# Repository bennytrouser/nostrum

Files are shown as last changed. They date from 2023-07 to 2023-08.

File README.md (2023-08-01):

# Nostrum
A 32 key ergo split keyboard with minimal splay.
- 3° Splay on pinky and ring columns
- Inspiration from the [Hummingbird](https://github.com/PJE66/hummingbird) style [Berylline](https://github.com/jcmkk3/trochilidae#berylline) by [jcmkk3](https://github.com/jcmkk3)
- Created with the wonderful [ergogen](https://github.com/ergogen/ergogen) and KiCad7. Case files created with Autodesk Fusion360.

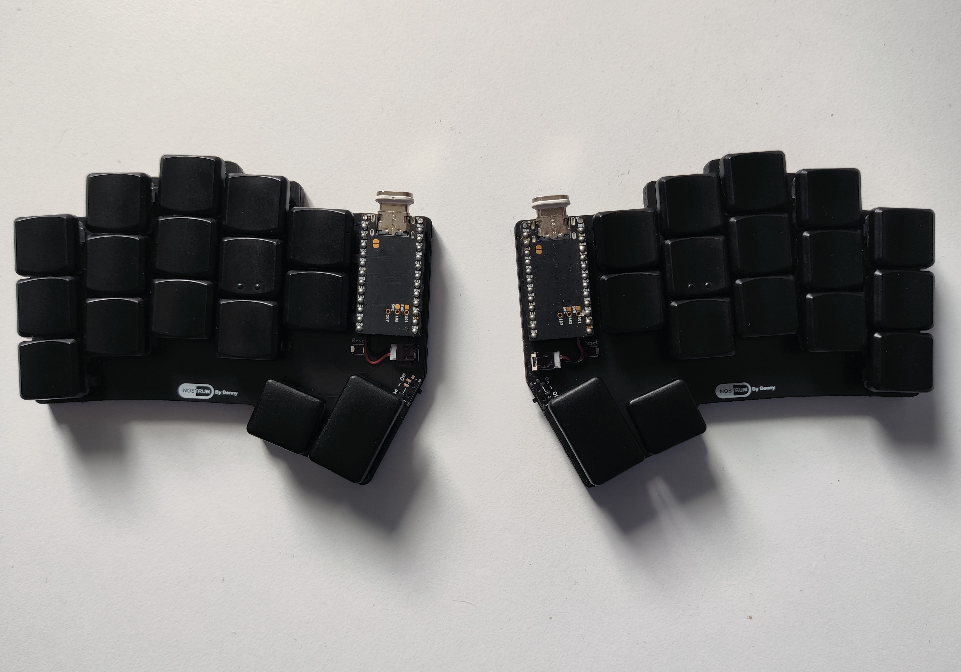
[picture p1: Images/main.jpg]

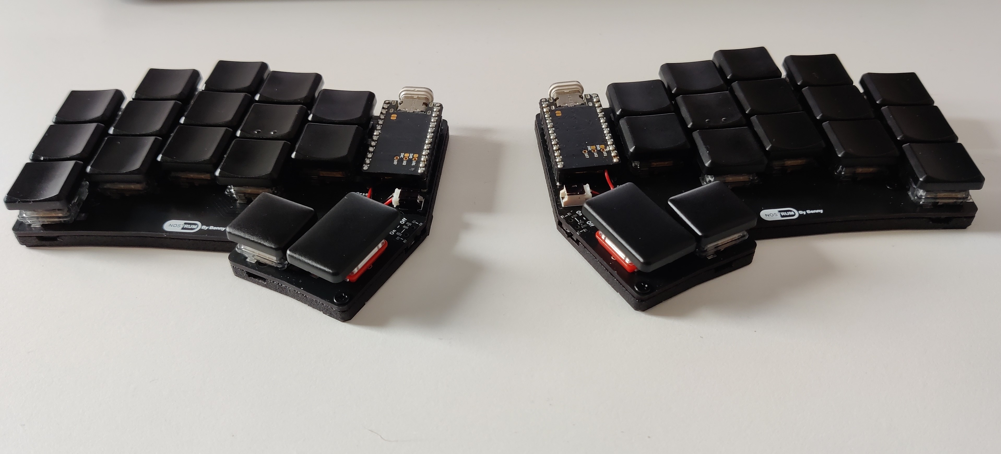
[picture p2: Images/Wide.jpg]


## PCB
| Top  | Bottom |
| --- | --- |
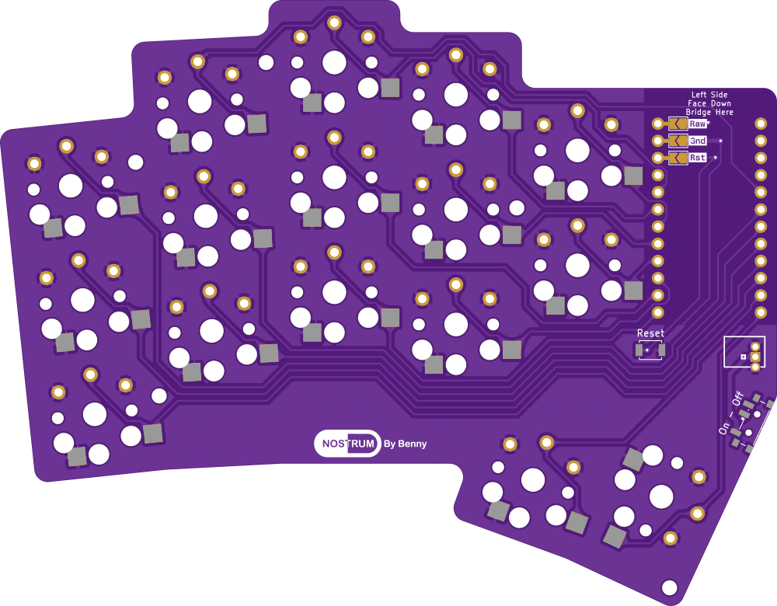
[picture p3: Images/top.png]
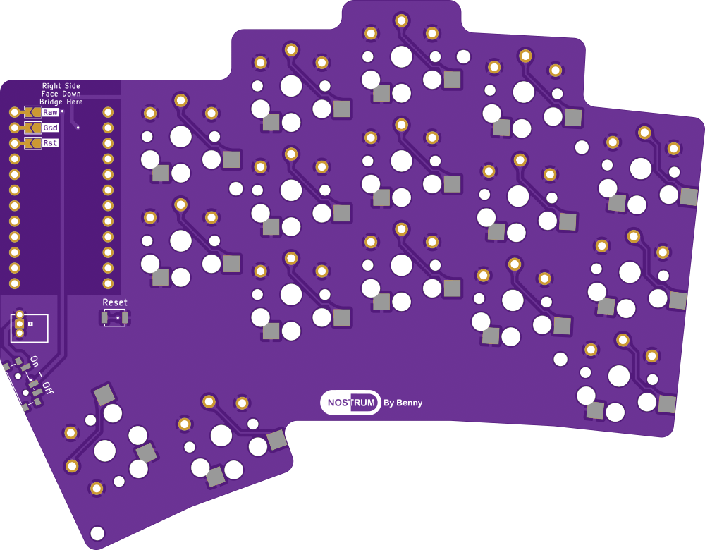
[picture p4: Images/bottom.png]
|   |  |

## Base Alpha Keymap
ColemakDH Based
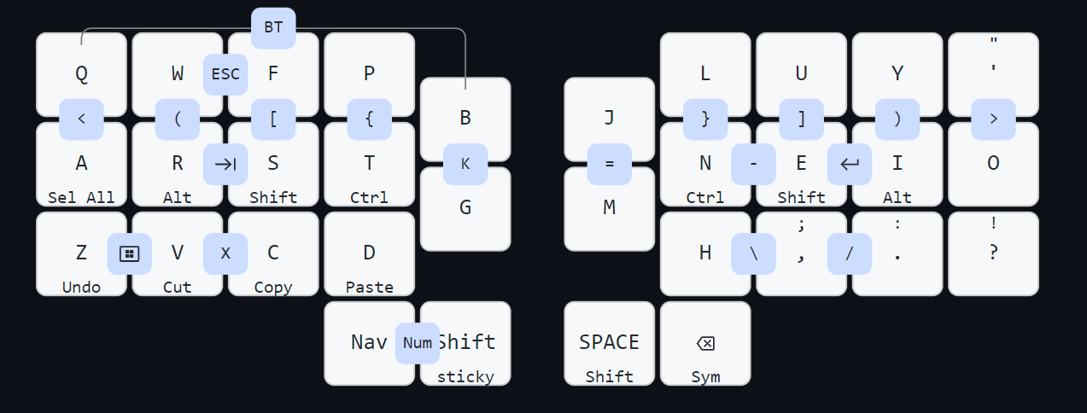
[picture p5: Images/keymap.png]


## Notes
- The reset and power switch can be mounted on either side. I think it works better with the case/bottom plate. 
- There is a hole on the base of the case to use a paper clip to activate the manual reset if mounted on the underside.
- The "feet" on the base are made from 1mm silicone rubber sheet as I prefer this to the standard bumpons.

## Warning
The original case was experimental. As such I have removed the files for the top part of the case and updated the bottom part that works great as a minimal bottom "tray". I have updated the STLs and pcb to avoid weakness on the mounting and to fix an issue with hotswaps causing fitment issues but I have not done a test print.

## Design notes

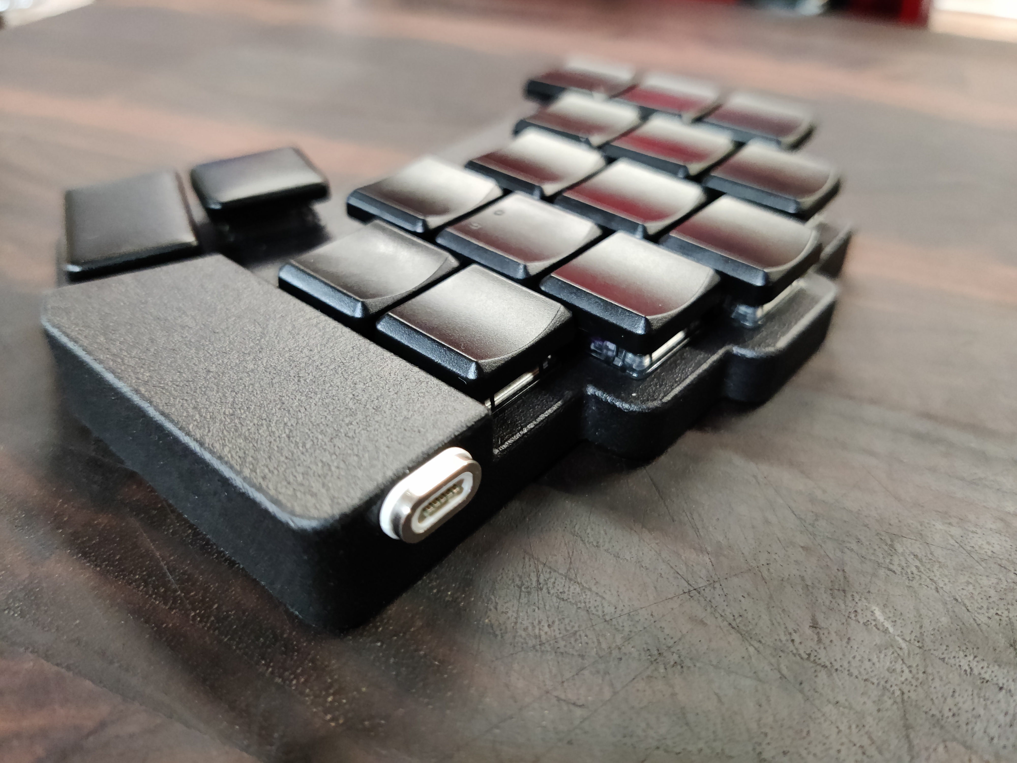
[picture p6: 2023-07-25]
Images/front.jpg

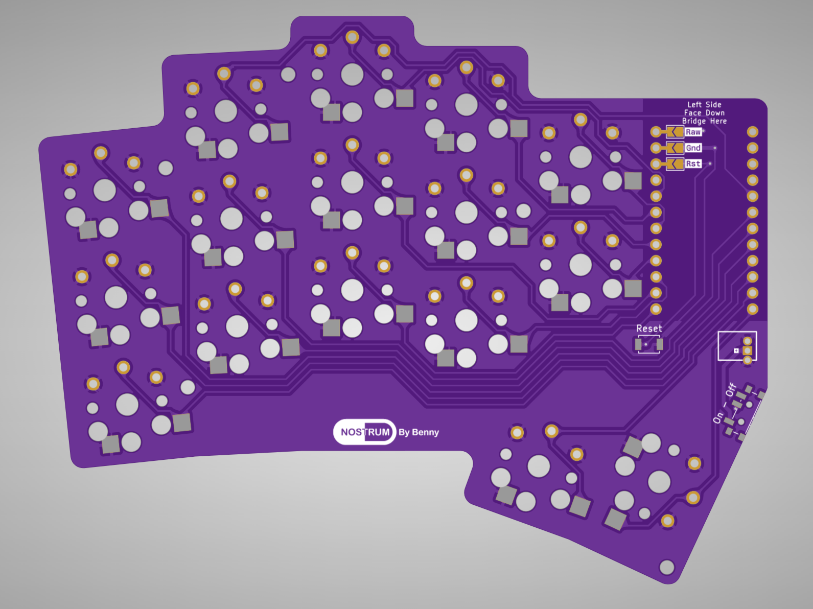
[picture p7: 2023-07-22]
Images/Nostrum_PCB.png

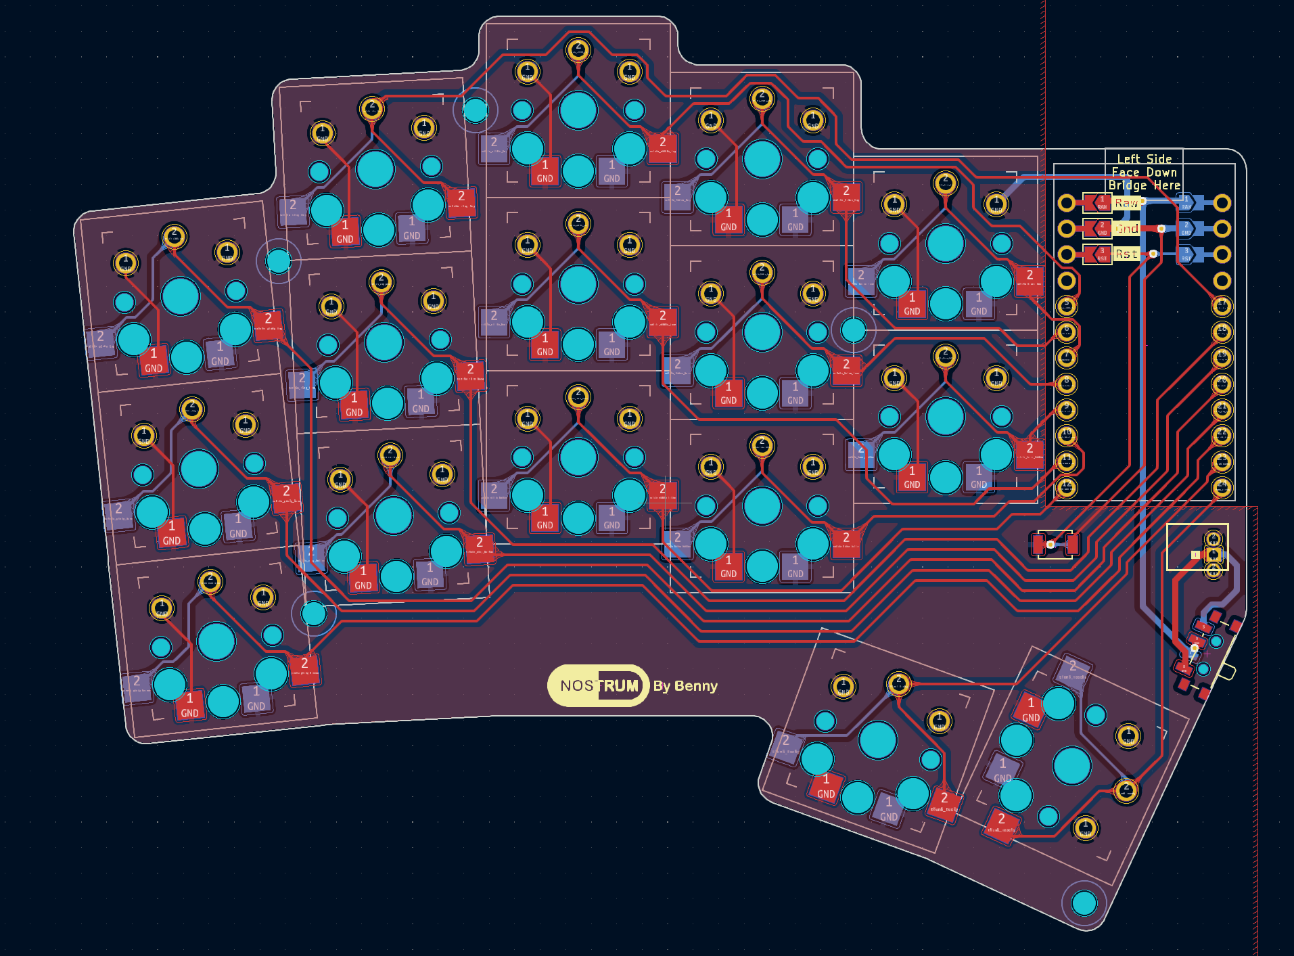
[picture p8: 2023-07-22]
Images/Nostrum_PCB_KiCad.png

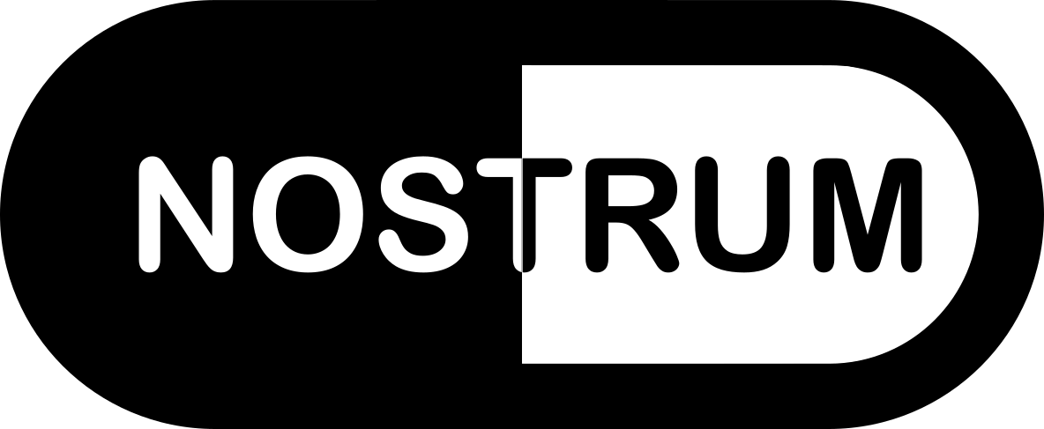
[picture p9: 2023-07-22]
Images/nostrum 2.png

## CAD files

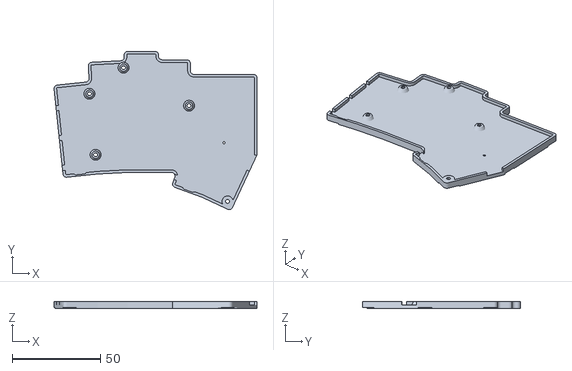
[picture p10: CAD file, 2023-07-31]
Files/Case STLs/Bottom Plate Left.stl
115.0 x 89.7 x 3.80

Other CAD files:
Files/Case STLs/Bottom Plate Right.stl

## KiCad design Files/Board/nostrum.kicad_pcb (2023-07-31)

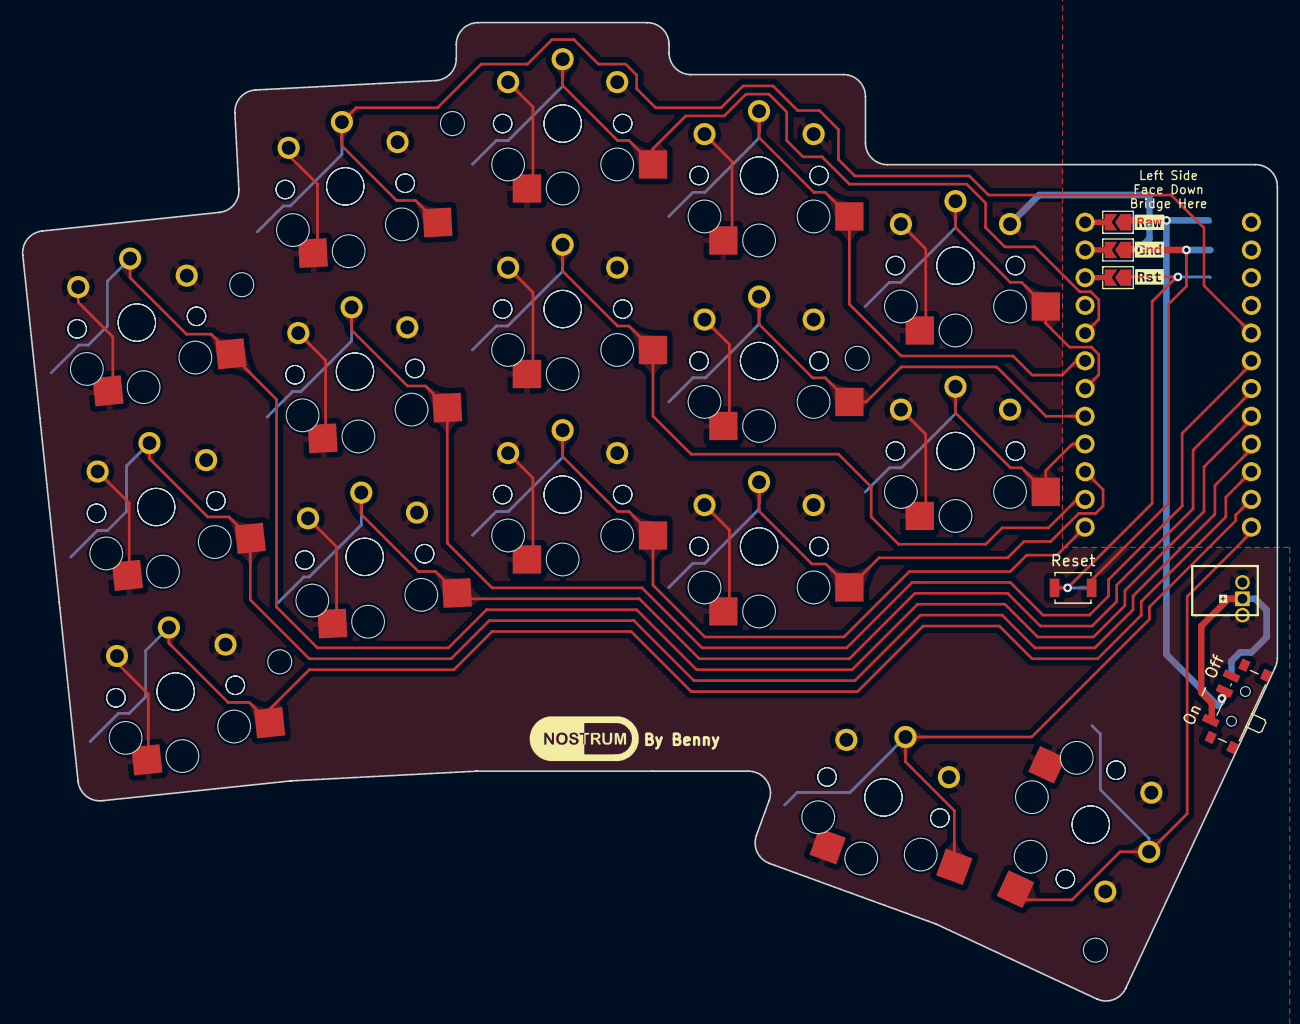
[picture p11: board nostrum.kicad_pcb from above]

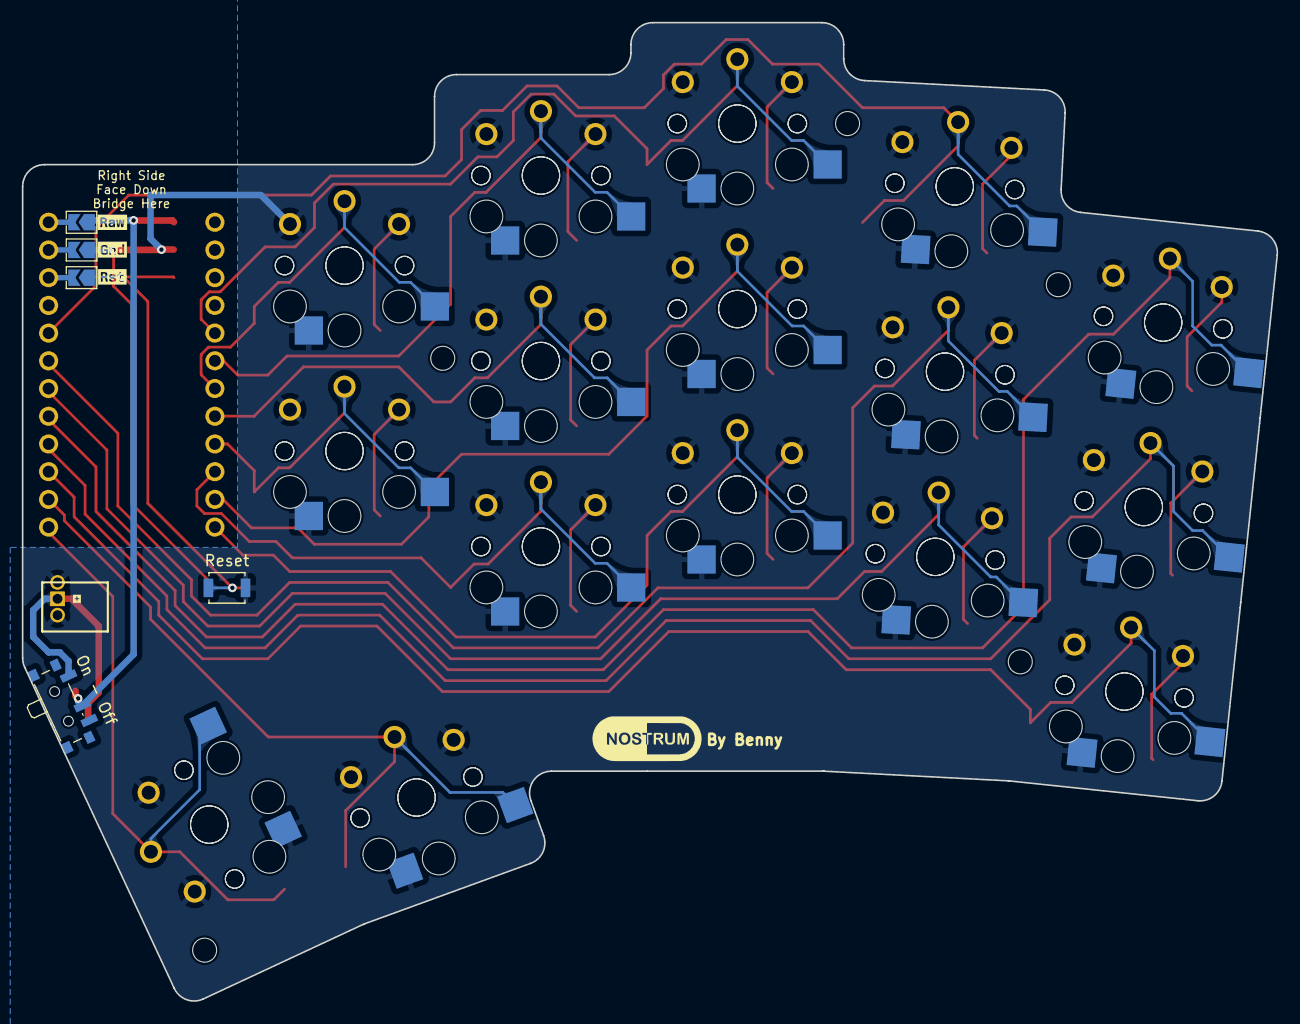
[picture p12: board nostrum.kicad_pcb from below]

Board: 2 copper layers, 115.0 x 89.7 mm, 43 parts (4 on the bottom side), 19 nets.

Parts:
MCU1: ProMicroSimpleJumper
On - Off: SW_SPDT_PCM12
Reset: SW_SPST_B3U-1000P
S1, S2, S3, S4, S5, S6, S7, S8, S9, S10, S11, S12, S13, S14, S15, S16, S17, S18, S19, S20, S21, S22, S23, S24, S25, S26, S27, S28, S29, S30, S31, S32: PG1350
kibuzzard-64BC4B3E: G***; kibuzzard-64BC4B3E
kibuzzard-64BC4B8B: G***; kibuzzard-64BC4B8B
kibuzzard-64BC4B21: G***; kibuzzard-64BC4B21
kibuzzard-64BC4B76: G***; kibuzzard-64BC4B76
kibuzzard-64BC4BA6: G***; kibuzzard-64BC4BA6
kibuzzard-64BC4CE6: G***; kibuzzard-64BC4CE6
kibuzzard-6498B72D, kibuzzard-6498B72D#2: G***; kibuzzard-6498B72D

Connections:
GND: MCU1.2, Reset.2, S1.1, S2.1, S3.1, S4.1, S5.1, S6.1, S7.1, S8.1, S9.1, S10.1, S11.1, S12.1, S13.1, S14.1, S15.1, S16.1, S17.1, S18.1, S19.1, S20.1, S21.1, S22.1, S23.1, S24.1, S25.1, S26.1, S27.1, S28.1, S29.1, S30.1, S31.1, S32.1
RAW: MCU1.1, On - Off.2
RST: MCU1.3, Reset.1
matrix_index_bottom: MCU1.10, S10.2, S26.2
matrix_index_home: MCU1.8, S11.2, S27.2
matrix_index_top: MCU1.6, S12.2, S28.2
matrix_inner_bottom: MCU1.9, S13.2, S29.2
matrix_inner_home: MCU1.7, S14.2, S30.2
matrix_middle_bottom: MCU1.12, S7.2, S23.2
matrix_middle_home: MCU1.11, S8.2, S24.2
matrix_middle_top: MCU1.5, S9.2, S25.2
matrix_pinky_bottom: MCU1.22, S1.2, S17.2
matrix_pinky_home: MCU1.21, S2.2, S18.2
matrix_pinky_top: MCU1.20, S3.2, S19.2
matrix_ring_bottom: MCU1.19, S4.2, S20.2
matrix_ring_home: MCU1.18, S5.2, S21.2
matrix_ring_top: MCU1.17, S6.2, S22.2
thumb_reachy: MCU1.24, S16.2, S32.2
thumb_tucky: MCU1.23, S15.2, S31.2

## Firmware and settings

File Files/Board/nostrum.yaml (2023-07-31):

units:
  # capx: 17        # Key cap size horizontal
  # capy: 16        # Key cap size vertical
  capx: 17.5   # Actual mbk size
  capy: 16.5   # Actual mbk size
  thumbcapx: 26.5 # Actual mbk 1.5u length
  kx: cx + 0.5    # Key spacing horizontal
  ky: cy + 0.5    # Key spacing vertical
  pinky_splay: 3  # Degrees of splay between pinky and ring columns
  pinky_adj: -10   # Adjustment to compensate for splay spacing
  ring_splay: 3
  ring_adj: -8
  middle_splay: 0
  middle_adj: 0
  thumb_offsetx: 0.25kx
  promicro_x: 33
  promicro_y: 18
  outx: 0.5capx +1  # Used for plate outlines
  outy: 0.5capy +1  # Used for plate outlines

points:
  zones.matrix:
    anchor:
      rotate: ring_splay + pinky_splay
    key:
      width: capx
      height: capy
      spread: cx      
      padding: cy
      autobind: false
    rows:
      bottom.bind: [1, 1, 1, 1]
      home.bind: [1, 1.5, 0, 1]
      top.bind: [1, 2, 0, 1]
    columns:
      pinky:
        rows:
          bottom.bind: [1, 1, 1, 1]
          home.bind: [1, 1.5, 0, 1]
          top.bind: [1, 2, 0, 1]
      ring:
        key:
          stagger: 0.55U
          splay: -pinky_splay
          origin: [0, pinky_adj]
        rows:
          bottom.bind: [1,1.5,11.9,0]
          home.bind: [1,1.5,0,1]
          top.bind: [1,2,1,1]
      middle:
        key:
          stagger: 0.25U
          splay: -ring_splay
          origin: [0, ring_adj]
        rows:
          bottom.bind: [1,1,17.1,0]
          home.bind: [1,1,0,1]
          top.bind: [1,1,0,1]
      index:
        key.stagger: -0.25U
        rows:
          bottom.bind: [1,1,12.341,1]
          home.bind: [1,1,0,1]
          top.bind: [1,1,0,1]
      inner:
        key.stagger: 0.5ky
        rows:
          top.skip: true
          bottom.bind: [1,2,22.590471307,1]
          home.bind: [1,2,20,1]
  zones.thumb:
    anchor:
      ref: matrix_index_top
      shift: [0.6u,-57]
      rotate: -20
    key:
      width: capx
      height: capy
      autobind: false
    rows:
      home:
    columns:
      left.key:
        name: thumb_tucky
        bind: [0,3,1,1] # U,R,D,L
      right.key:
        spread: kx+0.2
        stagger: 0.225kx
        rotate: -95
        name: thumb_reachy
        bind: [1,1,2,1.2191] # R,D,L,U

  # MCU
  zones.mcu:
    anchor:
      ref: matrix_inner_home
      shift: [19.5,-0.5cx]
      rotate: -90
    key:
      width: promicro_x
      height: promicro_y
      autobind: false
  # Power slider
  zones.pcm12:
    anchor:
      - ref: mcu
        shift: [0.5promicro_x + 12, 0.4promicro_y + 1]
        rotate: 180
    key:
      name: pcm12
      height: 2.6
      width: 6.7
  # Reset switch
  zones.reset:
    anchor:
      - ref: mcu
        shift: [.5promicro_x + 4, -0.5promicro_y + 10]    
    key:
      name: reset
      height: 3
      width: 2.5
  # JST
  zones.bat:
    anchor:
      - ref: mcu
        shift: [0.5promicro_x + 3.5, -0.5promicro_y + 3.25]
        rotate: 90
    key:
      name: bat
      height: 5
      width: 4.5

  # Mounting Holes
  zones.mount_tl:
    anchor:
      - ref: matrix_ring_home
        shift: [-0.5cx -0.95,0.5cy]
    key:
      name: mounthole_tl
      height: 2.2
      width: 2.2
      footprints:
  zones.mount_tr:
    anchor:
      - ref: matrix_inner_bottom
        shift: [-0.5cx,0.5cy]
    key:
      name: mounthole_tr
      height: 2.2
      width: 2.2
  zones.mount_tm:
    anchor:
      - ref: matrix_middle_top
        shift: [-0.5cx -1.1,0]
    key:
      name: mounthole_tm
      height: 2.2
      width: 2.2
  zones.mount_bl:
    anchor:
      - ref: matrix_ring_bottom
        shift: [-0.46cx,-0.6cy+1]
    key:
      name: mounthole_bl
      height: 2.2
      width: 2.2
  zones.mount_br:
    anchor:
      - ref: thumb_reachy
        shift: [0.5 thumbcapx -3,0.5 capy -3]
    key:
      name: mounthole_br
      height: 2.2
      width: 2.2
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

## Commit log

2023-07-31 STL and PCB fixes. Readme update
2023-08-23 xiao footprint
